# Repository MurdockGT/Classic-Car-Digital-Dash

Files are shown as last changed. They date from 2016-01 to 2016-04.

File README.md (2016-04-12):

# Classic-Car-Digital-Dash
Full digital monitoring of classic car with coolant fan control with Arduino Mega

Current Features  Tested

Coolant Temperature
	AC Delco 213-928 - Connected with 4.7k pull up resistor to create a voltage divider for 
	Arduino to read on port A0 Programmed range 41F to 248F
	Sensor is Non Linear, programmed multiple calibration points to correct the readings.

Intake Air Temp
	AC Delco 213-190 - Connected with 10k pull up resistor to create a voltage divider for 
	Arduino to read on port A1 Programmed range 32f to 158f
	Sensor is Non Linear, programmed multiple calibration points to correct the readings.

Oil Pressure 
	VDO type Oil pressure sender,100 psi,240-33 ohms,low 11 psi alarm/warning switch
	Sensor is linear.  Calculations will be made with 240 to 33 ohm range.  Low PSI warning will also
	be wired into arduino to trigger a low oil alarm.

Battery Level
	Will use a voltage divider and calibration. R1 will be 1m ohm and R2 will be 100k ohms. We will sence from the center
	of R1 and R2.  R2 will be grounded. R1 will go to positive on the battery.
Fan Control - Tempurature dependent with master switch on touchscreen for overide.

Future Additions - Code written, untested

Added code for 4Dsystem 7 inch touchscreen gauge cluster.

Fuel Level indicator  - Code is there for a 80 ohm sending unit, need to calibrate.  This can be adjust in circuit and code for other brand sending units.
	
Wideband Sensor - LSU 4.9 Wideband sensor and controller  14point7.com controller.

Intake manifold pressure   -  http://www.14point7.com/products/boost-vac-sensor

Fuel Pressure - Function is there, same sensor as the Oil pressure gauge.

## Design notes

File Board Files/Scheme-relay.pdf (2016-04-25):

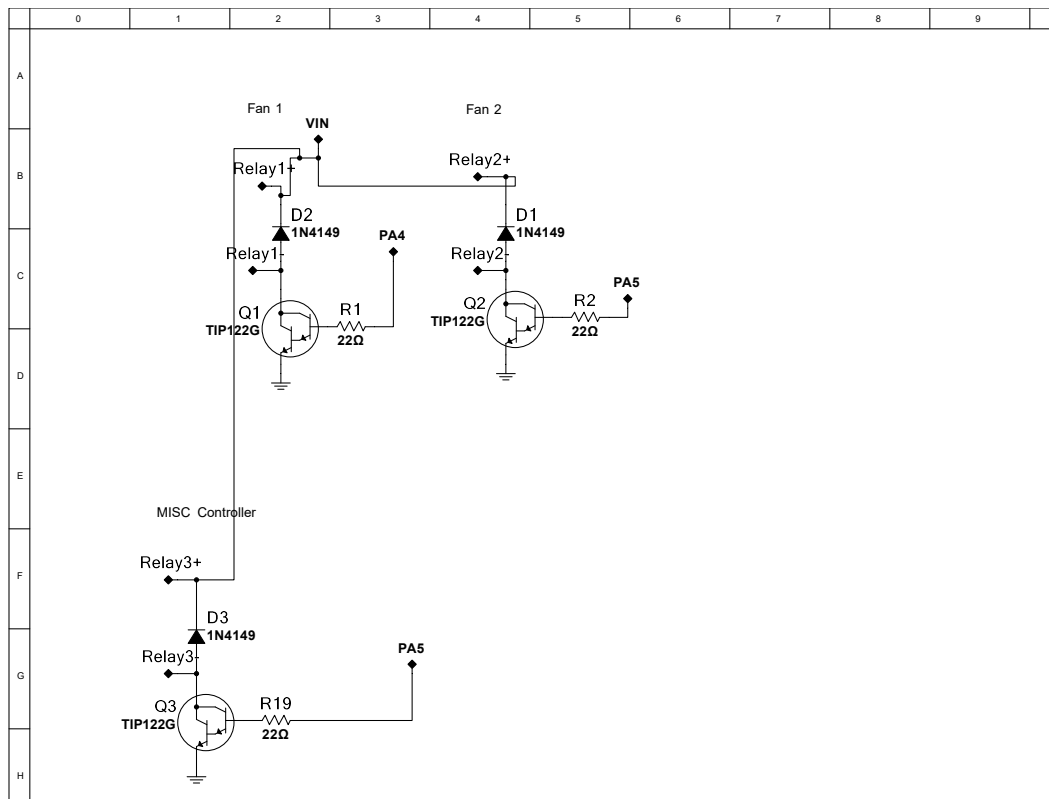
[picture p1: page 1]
TIP122G; Fan 1; Fan 2; MISC Controller; VIN

10 | 11 | 12 | 13 | 14

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
0 | 1 | 2 | 3 | 4 | 5 | 6 | 7 | 8 | 9

I

10 | 11 | 12 | 13 | 14 | I

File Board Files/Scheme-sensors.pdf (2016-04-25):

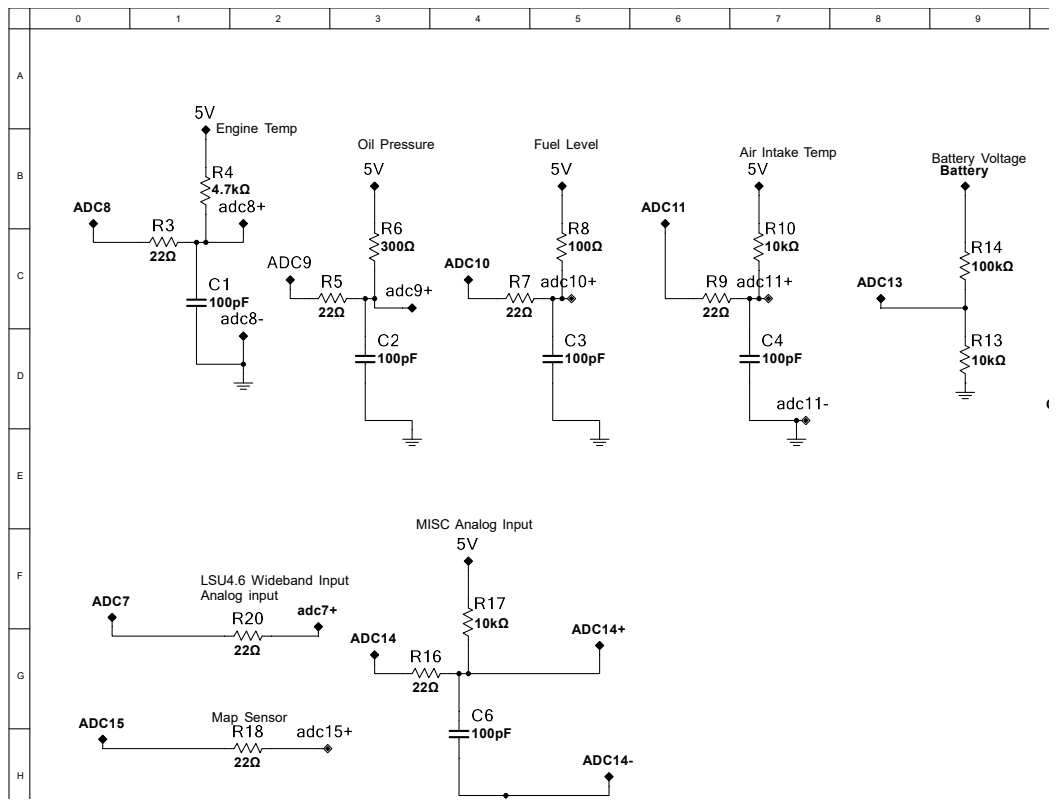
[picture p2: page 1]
Engine Temp; Oil Pressure; Fuel Level; Air Intake Temp; Battery Voltage; LSU4.6 Wideband Input Analog input; Map Sensor 22Ω; Battery; ADC8; ADC10; ADC11; ADC13; OPWL; ADC7; adc7+; ADC14; ADC14+; ADC14-; ADC15

MISC Analog Input

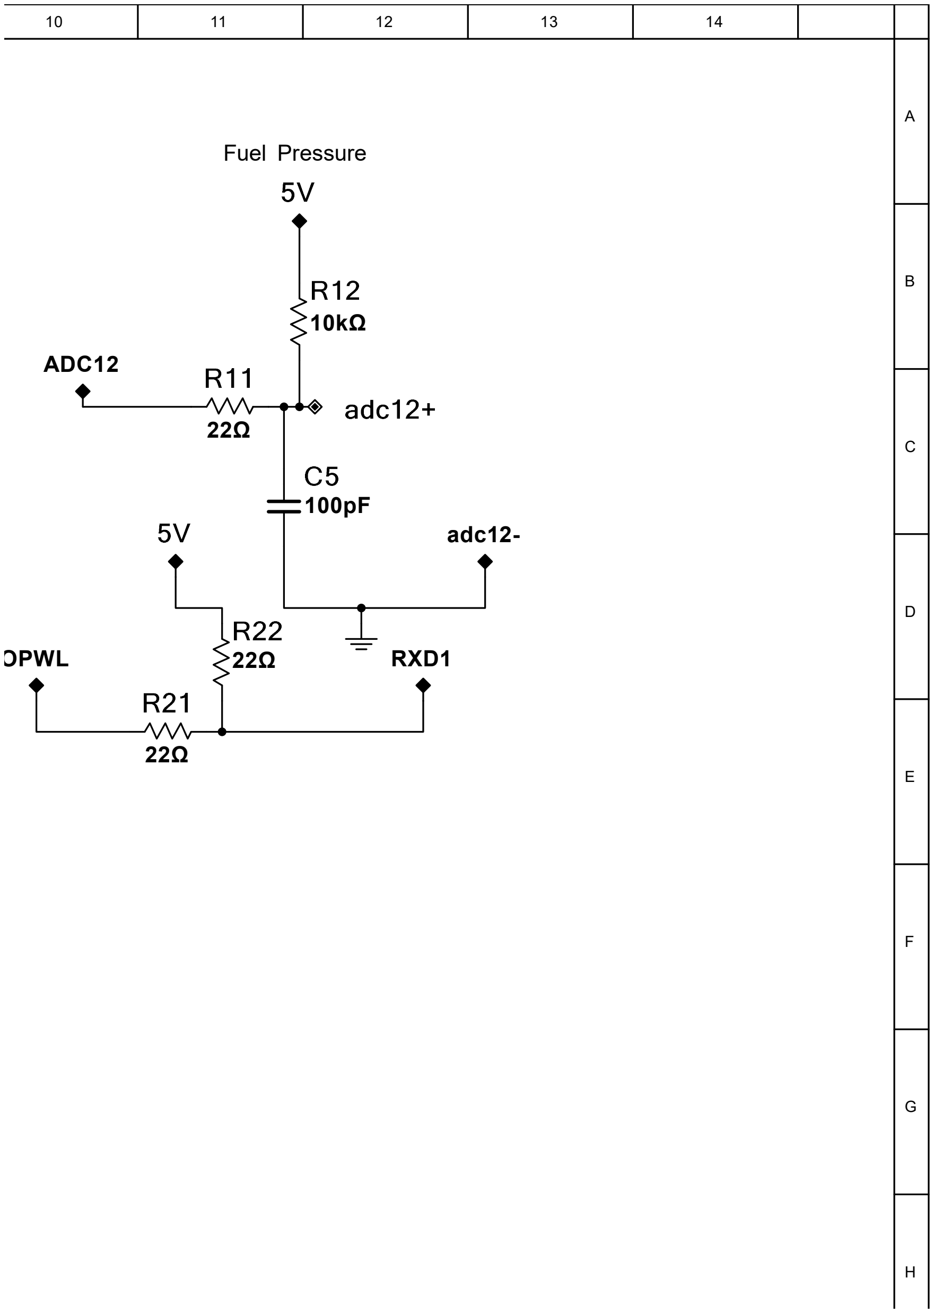
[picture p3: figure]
Fuel Pressure; OPWL; RXD1; ADC12; adc12-

0 | 1 | 2 | 3 | 4 | 5 | 6 | 7 | 8 | 9

I

10 | 11 | 12 | 13 | 14 | I

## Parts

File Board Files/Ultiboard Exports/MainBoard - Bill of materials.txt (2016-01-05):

Ultiboard Information Export File

Design Name  : MainBoard - Bill of materials
Report Date  : 5 January 2016
Report Time  : 06:34
--------------------------------------------------------------------------------

VALUE        SHAPE        #    REFDES       

1N4149       DO-35        3    D1,D2,D3     
4.7kOhm      RES1300-700X250 1    R4           
10kOhm       RES1300-700X250 4    R10,R12,R13,R17
22Ohm        RES1300-700X250 14   R1,R2,R3,R5,R7,R9,R11,R15,R16,R18,R19,R20,R21,R22
100kOhm      RES1300-700X250 1    R14          
100pF        CAPR508-381X254X584 6    C1,C2,C3,C4,C5,C6
100Ohm       RES1300-700X250 1    R8           
300Ohm       RES1300-700X250 1    R6           
HDR1X2       HDR1X2       1    12VIN        
HDR1X3       HDR1X3       1    SERIAL       
HDR1X8       Arduino_HDR1X8 5    ADCH,ADCL,COMMUNICATION,POWER,PWML
HDR1X10      Arduino_HDR1X10 1    JP6          
HDR2X3       HDR2X3       2    RELAY,SDCARD 
HDR2X18      Arduino_HDR2X18 1    XIO          
RIBBON_16V   FKV16SN      1    Sensors      
TIP122G      TO254P482X997X1925-3P 3    Q1,Q2,Q3

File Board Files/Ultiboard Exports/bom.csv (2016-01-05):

RefDes | Value | Shape | Locked | Trace clearance | Part spacing | Pin swap | Gate swap | Part group
12VIN | HDR1X2 | HDR1X2 | No | 0.000000 | Use design rule defaults | Yes | Internal gates only | No group
ADCH | HDR1X8 | Arduino_HDR1X8 | Yes | 0.254000 | Use design rule defaults | Yes | Internal gates only | No group
ADCL | HDR1X8 | Arduino_HDR1X8 | Yes | 0.254000 | Use design rule defaults | Yes | Internal gates only | No group
C1 | 100pF | CAPR508-381X254X584 | No | 0.254000 | Use design rule defaults | Yes | Internal gates only | No group
C2 | 100pF | CAPR508-381X254X584 | No | 0.254000 | Use design rule defaults | Yes | Internal gates only | No group
C3 | 100pF | CAPR508-381X254X584 | No | 0.254000 | Use design rule defaults | Yes | Internal gates only | No group
C4 | 100pF | CAPR508-381X254X584 | No | 0.254000 | Use design rule defaults | Yes | Internal gates only | No group
C5 | 100pF | CAPR508-381X254X584 | No | 0.254000 | Use design rule defaults | Yes | Internal gates only | No group
C6 | 100pF | CAPR508-381X254X584 | No | 0.254000 | Use design rule defaults | Yes | Internal gates only | No group
COMMUNICATION | HDR1X8 | Arduino_HDR1X8 | Yes | 0.254000 | Use design rule defaults | Yes | Internal gates only | No group
D1 | 1N4149 | DO-35 | No | 0.254000 | Use design rule defaults | Yes | Internal gates only | No group
D2 | 1N4149 | DO-35 | No | 0.254000 | Use design rule defaults | Yes | Internal gates only | No group
D3 | 1N4149 | DO-35 | No | 0.254000 | Use design rule defaults | Yes | Internal gates only | No group
JP6 | HDR1X10 | Arduino_HDR1X10 | Yes | 0.254000 | Use design rule defaults | Yes | Internal gates only | No group
POWER | HDR1X8 | Arduino_HDR1X8 | Yes | 0.254000 | Use design rule defaults | Yes | Internal gates only | No group
PWML | HDR1X8 | Arduino_HDR1X8 | Yes | 0.254000 | Use design rule defaults | Yes | Internal gates only | No group
Q1 | TIP122G | TO254P482X997X1925-3P | No | 0.254000 | Use design rule defaults | Yes | Internal gates only | No group
Q2 | TIP122G | TO254P482X997X1925-3P | No | 0.254000 | Use design rule defaults | Yes | Internal gates only | No group
Q3 | TIP122G | TO254P482X997X1925-3P | No | 0.254000 | Use design rule defaults | Yes | Internal gates only | No group
R1 | 22Ohm | RES1300-700X250 | No | 0.254000 | Use design rule defaults | Yes | Internal gates only | No group
R2 | 22Ohm | RES1300-700X250 | No | 0.254000 | Use design rule defaults | Yes | Internal gates only | No group
R3 | 22Ohm | RES1300-700X250 | No | 0.254000 | Use design rule defaults | Yes | Internal gates only | No group
R4 | 4.7kOhm | RES1300-700X250 | No | 0.254000 | Use design rule defaults | Yes | Internal gates only | No group
R5 | 22Ohm | RES1300-700X250 | No | 0.254000 | Use design rule defaults | Yes | Internal gates only | No group
R6 | 300Ohm | RES1300-700X250 | No | 0.254000 | Use design rule defaults | Yes | Internal gates only | No group
R7 | 22Ohm | RES1300-700X250 | No | 0.254000 | Use design rule defaults | Yes | Internal gates only | No group
R8 | 100Ohm | RES1300-700X250 | No | 0.254000 | Use design rule defaults | Yes | Internal gates only | No group
R9 | 22Ohm | RES1300-700X250 | No | 0.254000 | Use design rule defaults | Yes | Internal gates only | No group
R10 | 10kOhm | RES1300-700X250 | No | 0.254000 | Use design rule defaults | Yes | Internal gates only | No group
R11 | 22Ohm | RES1300-700X250 | No | 0.254000 | Use design rule defaults | Yes | Internal gates only | No group
R12 | 10kOhm | RES1300-700X250 | No | 0.254000 | Use design rule defaults | Yes | Internal gates only | No group
R13 | 10kOhm | RES1300-700X250 | No | 0.254000 | Use design rule defaults | Yes | Internal gates only | No group
R14 | 100kOhm | RES1300-700X250 | No | 0.254000 | Use design rule defaults | Yes | Internal gates only | No group
R15 | 22Ohm | RES1300-700X250 | No | 0.254000 | Use design rule defaults | Yes | Internal gates only | No group
R16 | 22Ohm | RES1300-700X250 | No | 0.254000 | Use design rule defaults | Yes | Internal gates only | No group
R17 | 10kOhm | RES1300-700X250 | No | 0.254000 | Use design rule defaults | Yes | Internal gates only | No group
R18 | 22Ohm | RES1300-700X250 | No | 0.254000 | Use design rule defaults | Yes | Internal gates only | No group
R19 | 22Ohm | RES1300-700X250 | No | 0.254000 | Use design rule defaults | Yes | Internal gates only | No group
R20 | 22Ohm | RES1300-700X250 | No | 0.254000 | Use design rule defaults | Yes | Internal gates only | No group
R21 | 22Ohm | RES1300-700X250 | No | 0.254000 | Use design rule defaults | Yes | Internal gates only | No group
R22 | 22Ohm | RES1300-700X250 | No | 0.254000 | Use design rule defaults | Yes | Internal gates only | No group
RELAY | HDR2X3 | HDR2X3 | No | 0.000000 | Use design rule defaults | Yes | Internal gates only | No group
SDCARD | HDR2X3 | HDR2X3 | No | 0.000000 | Use design rule defaults | Yes | Internal gates only | No group
Sensors | RIBBON_16V | FKV16SN | No | 0.000000 | Use design rule defaults | Yes | Internal gates only | No group
SERIAL | HDR1X3 | HDR1X3 | No | 0.000000 | Use design rule defaults | Yes | Internal gates only | No group
XIO | HDR2X18 | Arduino_HDR2X18 | Yes | 0.254000 | Use design rule defaults | Yes | Internal gates only | No group

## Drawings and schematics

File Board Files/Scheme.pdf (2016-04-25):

SC1

## Tach

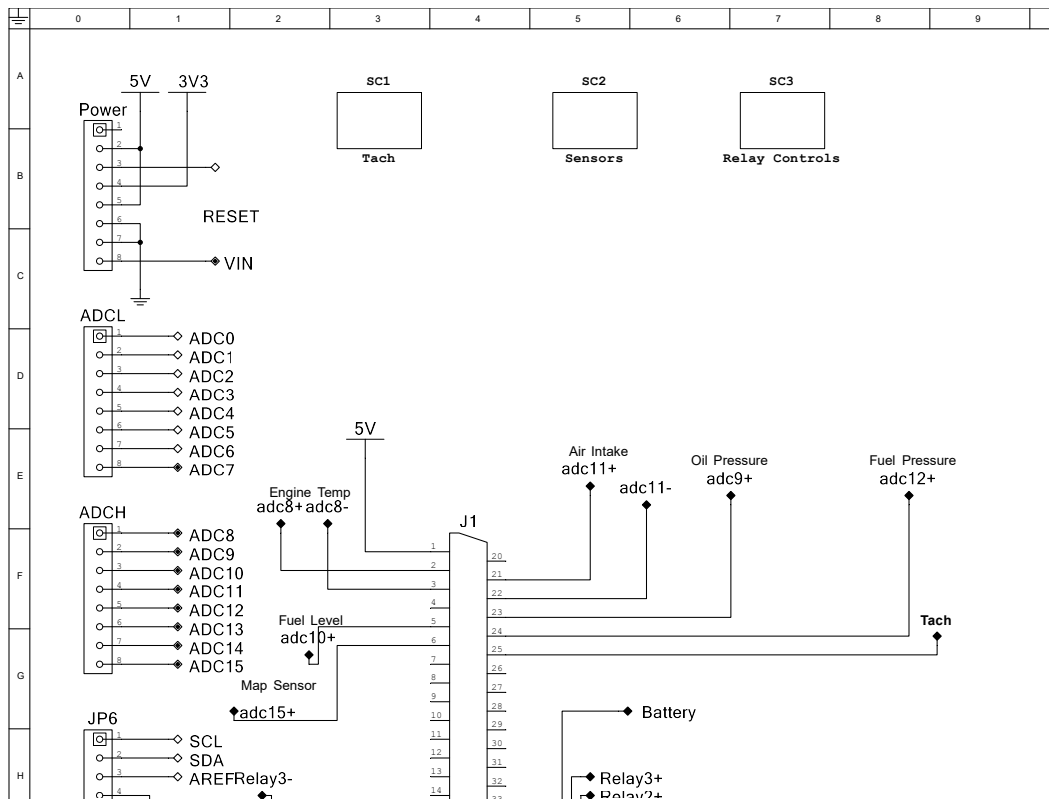
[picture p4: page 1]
Sensors; Relay Controls; Engine Temp; Air Intake; Oil Pressure; Fuel Level; Fuel Pressure; Map Sensor; Tach

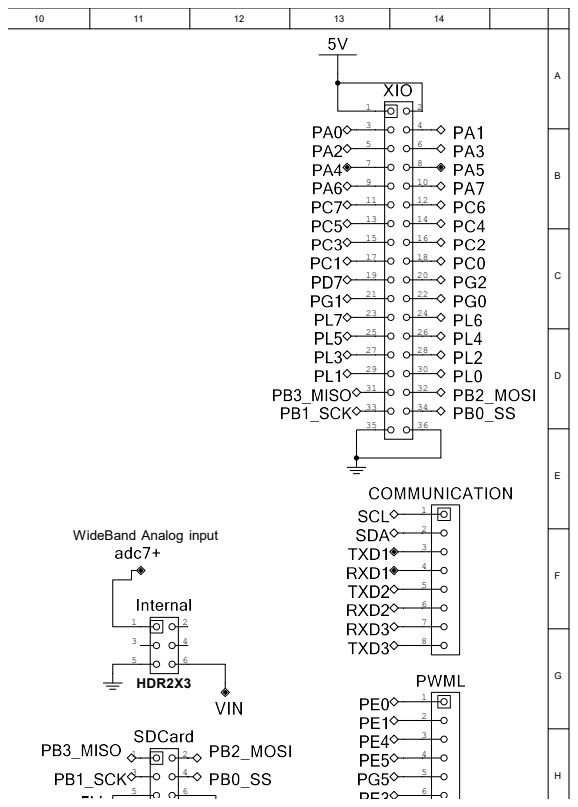
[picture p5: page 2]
HDR2X3

WideBand Analog input

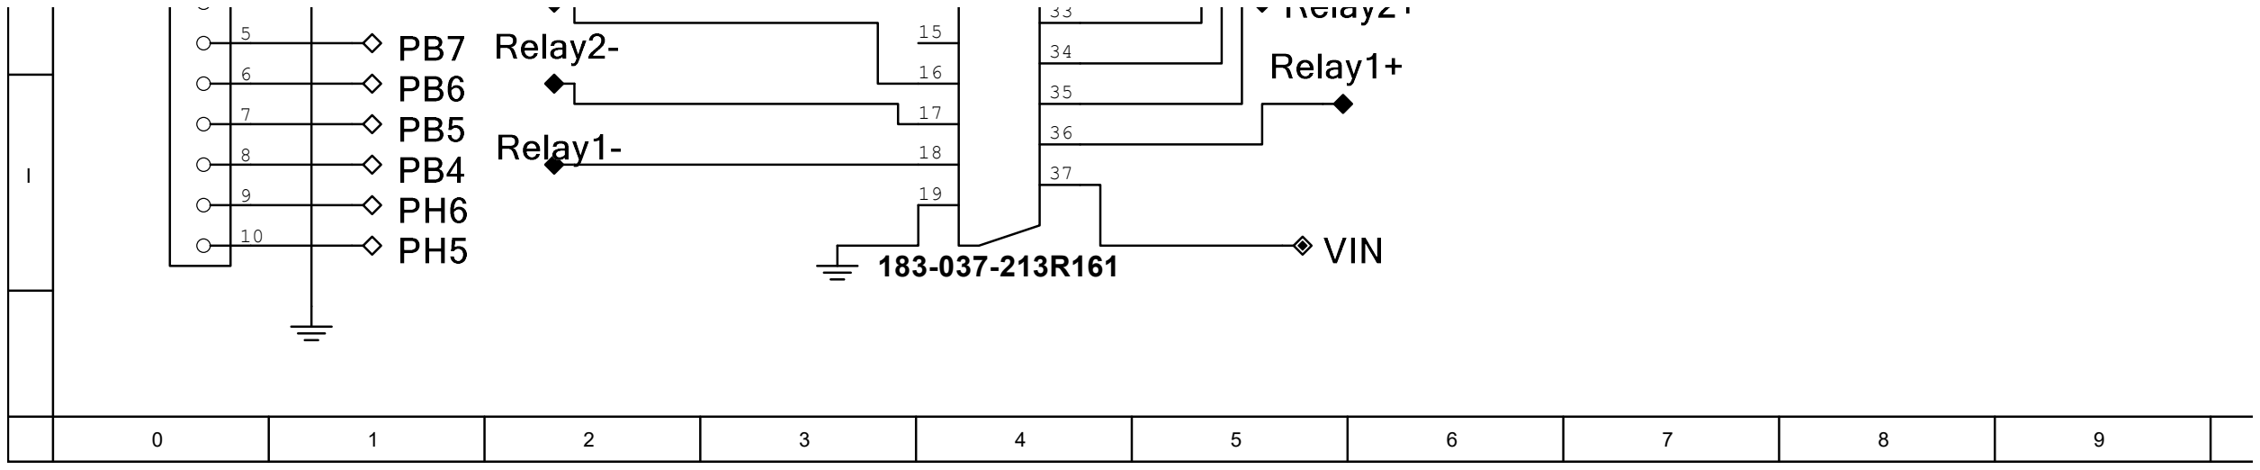
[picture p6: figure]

## HDR2X3

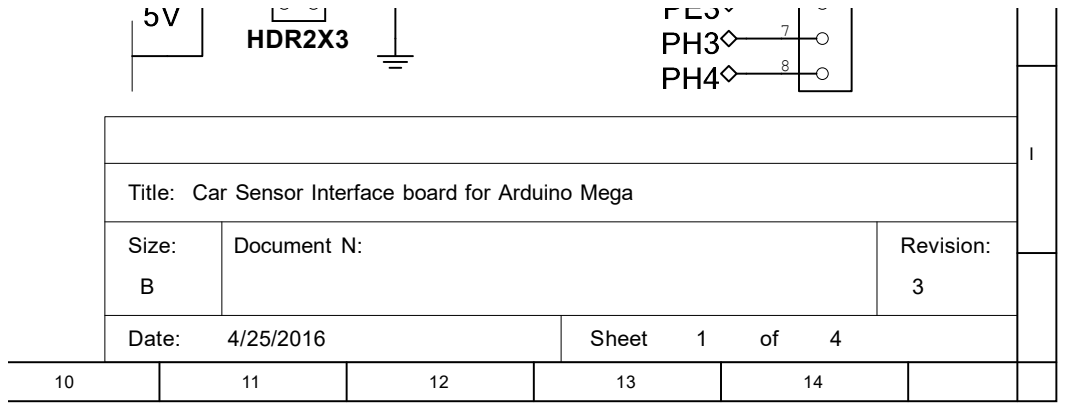
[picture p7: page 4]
Title:; Document N:; Date:; Sheet; Size:; Revision:

Car Sensor Interface board for Arduino Mega

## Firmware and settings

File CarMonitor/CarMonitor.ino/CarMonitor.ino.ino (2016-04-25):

#include <genieArduino.h>
#include <Wire.h>
#include <math.h>
#include <EEPROM.h>
// #include <Time.h>


// Configuration
int targetCoolantTemp = 180; // this is the target for the fans to turn on.
int targetChokeTemp = 120;// set a tempurature that you want the choke to be turned off at.
int fuelGaugeOhms = 80;


// analog pins

const byte AFRatioPin = A7; // pin for LSU 4.9 O2 sensor controller linear output
const byte coolantTempPin = A8; // pin for coolant temp
const byte oilPressPin = A9; // pin for oil pressure
const byte fuelLevelPin = A10; // pin for fuel level
const byte iatTempPin = A11;  // Air intake temperature
const byte fuelPressPin = A12; // Fuel Line Pressure Pin
const byte battVoltagePin = A13; // pin for battery voltage
const byte MiscAnalogInput = A14;  // Placeholder for another analog input. Not used as of now, but circuit is there on board.
const byte intakePressPin = A15; // pin for intake manifold pressure (vac or boost)

// analog input setup
const float aRef = 5.0; // analog reference for board (Volts)
const float regVoltage = 5.0; // instrument unit voltage regulator output (Volts)

//digital Pins

const byte oilWarninglight = 18; // pin for showing if oil pressure has dropped below 11 psi
const byte wireSDAPin = 20; // I2C SDA
const byte wireSCLPin = 21; // I2C SCL

// Fan status Bool
int switch1Val;
bool fanStatus1 = 0;
bool fanStatus2 = 0;

// Steinhart–Hart equation parameters for coolant temp sender
// http://en.wikipedia.org/wiki/Thermistor
const float SHparamA = 1.869336e-3;
const float SHparamB = 2.723037e-4;
const float SHparamC = 2.833889e-7;

unsigned long previousMillis = 0; // for sensor refresh interval

// engine info
byte engineCylinders = 8; // for future use

int displacement = 302; // (units of cu in) for MAFR calculations
int refreshInterval = 750; // milliseconds between sensor updates


//configuration for the Tachometer variables
byte engineCycles = 4; // for tach calculation :Future use
const int tachSensorPin = 19;
const int sensorInterrupt = 4;
const int timeoutValue = 5;
volatile unsigned long lastPulseTime;
volatile unsigned long interval = 0;
volatile int timeoutCounter;
int rpm;
int rpmlast = 3000;
int rpm_interval = 3000;
const int fanOut1 = 6; // need to move from pin 4 to pin 6, Screen needs this for reset, will move it on next test board to pin 6.
const int fanOut2 = 5;
const int eChoke = 22;  // Pin assignment for Choke engagment if you have an electronic choke.

Genie genie;
#define RESETLINE 2  // Change this if you are not using an Arduino Adaptor Shield Version 2 (see code below)

void setup() {
  Serial.begin(200000);  // Serial0 @ 200000 (200K) Baud
  genie.Begin(Serial);   // Use Serial0 for talking to the Genie Library, and to the 4D Systems display

  genie.AttachEventHandler(myGenieEventHandler); // Attach the user function Event Handler for processing events
  // Reset the Display (change D4 to D2 if you have original 4D Arduino Adaptor)
  // THIS IS IMPORTANT AND CAN PREVENT OUT OF SYNC ISSUES, SLOW SPEED RESPONSE ETC
  // If NOT using a 4D Arduino Adaptor, digitalWrites must be reversed as Display Reset is Active Low, and
  // the 4D Arduino Adaptors invert this signal so must be Active High.
  pinMode(RESETLINE, OUTPUT);  // Set D4 on Arduino to Output (4D Arduino Adaptor V2 - Display Reset)
  digitalWrite(RESETLINE, 1);  // Reset the Display via D4
  delay(100);
  digitalWrite(RESETLINE, 0);  // unReset the Display via D4

  delay (3500); //let the display start up after the reset (This is important)

  // Set the brightness/Contrast of the Display - (Not needed but illustrates how)
  // Most Displays, 1 = Display ON, 0 = Display OFF. See below for exceptions and for DIABLO16 displays.
  // For uLCD-43, uLCD-220RD, uLCD-70DT, and uLCD-35DT, use 0-15 for Brightness Control, where 0 = Display OFF, though to 15 = Max Brightness ON.
  genie.WriteContrast(15);

  //Write a string to the Display to show the version of the library used
  genie.WriteStr(0, GENIE_VERSION);

  Serial.begin(9600); // initialize serial communication at 9600 bits per second:
  // Fan Pin Setup
  pinMode(fanOut1, OUTPUT);
  pinMode(fanOut2, OUTPUT);
  pinMode(eChoke, OUTPUT);
  digitalWrite(fanOut1, LOW);
  digitalWrite(fanOut2, LOW);
  // Tach Setup
  pinMode(tachSensorPin, INPUT);
  attachInterrupt(sensorInterrupt, sensorIsr, RISING);
  lastPulseTime = micros();
  timeoutCounter = 0;


}





// the loop routine runs over and over again forever:
void loop() {

  static long waitPeriod = millis(); // Time now

  static int gaugeOilp = getOilpressure();
  static int gaugeEngineTemp = getCoolantTemp();
  static int gaugeIntakeTemp = getIATtemp();
  static int gaugeIntakePress = getIntakePress();
  static int gaugeVoltage = getBattVoltage();
  static int gaugeRPM = getRPM();
  static int gaugeAFratio = getAFRatio();
  static int gaugeFuelPress = getFuelPress();
  static int gaugeFuelLevel = getFuelLevel();

  fanControl(gaugeEngineTemp); // controls fan

  // write the values to the 4DS Screen.
  // Gauge name, Gauge number, Gauge Value
  genie.WriteObject(GENIE_OBJ_COOL_GAUGE, 0, gaugeAFratio); //GENIE_OBJ_ANGULAR_METER
  genie.WriteObject(GENIE_OBJ_COOL_GAUGE, 1, gaugeRPM);
  genie.WriteObject(GENIE_OBJ_ANGULAR_METER, 0, gaugeIntakeTemp);
  genie.WriteObject(GENIE_OBJ_ANGULAR_METER, 1, gaugeEngineTemp);
  genie.WriteObject(GENIE_OBJ_ANGULAR_METER, 2, gaugeVoltage);
  genie.WriteObject(GENIE_OBJ_ANGULAR_METER, 3, gaugeFuelLevel);
  genie.WriteObject(GENIE_OBJ_ANGULAR_METER, 4, gaugeIntakePress);
  genie.WriteObject(GENIE_OBJ_ANGULAR_METER, 5, gaugeOilp);

  genie.ReadObject(GENIE_OBJ_4DBUTTON, 0);

}
void myGenieEventHandler(void)
{
  genieFrame Event;
  genie.DequeueEvent(&Event); // Remove the next queued event from the buffer, and process it below


  if (genie.EventIs(&Event, GENIE_REPORT_OBJ, GENIE_OBJ_4DBUTTON, 0))
  { //if the event is a REPORT_OBJ from 4DBUTTON3
    switch1Val = genie.GetEventData(&Event);  //extract the MSB and LSB values and pass them to rockersw_val

  }

}
int getCoolantTemp()
{
  // Using AC Delco/GM 2 wire temp sensor.
  float array[44] = {
    // Voltage From Sensor on left // Corresponding Temprature on right  ,
    //You find this by using voltage divider forumla. Current set is for a 4.7k ohm R1 and R2 is your ACdelco Temp Sensor
    2.429165  , 15 ,
    2.137986  , 20 ,
    1.864576  , 25 ,
    1.613833  , 30 ,
    1.38795   , 35 ,
    1.188159  , 40,
    1.013571  , 45,
    0.8626761 , 50,
    0.734253  , 55,
    0.6246509 , 60,
    0.5314699 , 65,
    0.4536661 , 70,
    0.3876349 , 75,
    0.3317441 , 80,
    0.286803  , 85,
    0.2446477 , 90,
    0.2110208 , 95,
    0.1824518 , 100,
    0.1582331 , 105,
    0.1376963 , 110,
    0.1201279 , 115,
    0.1050845 , 120,
  };

  int val = 0;
  for (int i = 1; i <= 10; i++)
  {
    val += analogRead(coolantTempPin);
  }
  val += 5; // allows proper rounding due to using integer math
  val /= 10; // get average value
  float voltage = val / 1023.0 * aRef;
  float tempr;
  if (voltage >= array[0])
  {
    tempr = array[1];
  }
  else if (voltage <= array[42])
  {
    tempr = array[43];
  }
  else
  {
    for (int i = 1; i < 44; i++)
    {
      int ii = 2 * i;
      if (voltage <= array[ii] && voltage >= array[ii + 2])
      {
        tempr = array[ii + 1] + ((array[ii + 3] - array[ii + 1]) * (voltage - array[ii]) / (array[ii + 2] - array[ii]));
        break;
      }
    }
  }
  int temprF = tempr * 1.8 + 32;
  return temprF;
}
int getOilpressure()
{
  // using VDO Oil Pressure guage, 100PSI
  float array[12] = {
    // Voltage From Sensor on left // Corresponding Temprature on right  ,
    //You find this by using voltage divider forumla. Current set is for a 330 ohm R1 and R2 is your VDO Oil Pressure sensor

    2.105263 , 0.1,
    1.944444 , 14.5,
    1.764706 , 29,
    1.5625 , 43.5,
    1.071429 , 72.5,
    0.4141189 , 100,
  };
  int val = 0;
  for (int i = 1; i <= 10; i++)
  {
    val += analogRead(oilPressPin);
  }
  val += 5; // allows proper rounding due to using integer math
  val /= 10; // get average value
  float voltage = val / 1023.0 * aRef;

  float oilp;
  if (voltage >= array[0])
  {
    oilp = array[1];
  }
  else if (voltage <= array[10])
  {
    oilp = array[11];
  }
  else
  {
    for (int i = 1; i < 12; i++)
    {
      int ii = 2 * i;
      if (voltage <= array[ii] && voltage >= array[ii + 2])
      {
        oilp = array[ii + 1] + ((array[ii + 3] - array[ii + 1]) * (voltage - array[ii]) / (array[ii + 2] - array[ii]));
        break;
      }
    }
  }
  int oilpres = oilp;
  return oilpres;
}
int getIATtemp()
{

  float array[30] = {
    // Voltage From Sensor on left // Corresponding Temprature on right  ,
    //You find this by using voltage divider forumla. Current set is for a 10k ohm R1 and R2 is your ACdelco Temp Sensor

    2.403407 , 0,
    2.085058 , 5,
    1.789109 , 10,
    1.526089 , 15,
    1.284462 , 20,
    1.079046 , 25,
    0.9033183 , 30,
    0.7547971 , 35,
    0.6305165 , 40,
    0.5265277 , 45,
    0.4400365 , 50,
    0.3686551 , 55,
    0.3095685 , 60,
    0.2611127 , 65,
    0.2207991 , 70,


  };

  int val = 0;
  for (int i = 1; i <= 10; i++)
  {
    val += analogRead(iatTempPin);
  }
  val += 5; // allows proper rounding due to using integer math
  val /= 10; // get average value
  float voltage = val / 1023.0 * aRef;



  float temprIAT;
  if (voltage >= array[0])
  {
    temprIAT = array[1];
  }
  else if (voltage <= array[28])
  {
    temprIAT = array[29];
  }
  else
  {
    for (int i = 1; i < 44; i++)
    {
      int ii = 2 * i;
      if (voltage <= array[ii] && voltage >= array[ii + 2])
      {
        temprIAT = array[ii + 1] + ((array[ii + 3] - array[ii + 1]) * (voltage - array[ii]) / (array[ii + 2] - array[ii]));
        break;
      }
    }
  }
  int temprFIAT = temprIAT * 1.8 + 32;
  return temprFIAT;
}
float getIntakePress()
{
  // will need to test with this sensor and moddify from there.
  // http://www.14point7.com/products/boost-vac-sensor
  // take 10 readings and sum them
  int val = 0;
  for (int i = 1; i <= 10; i++)
  {
    val += analogRead(intakePressPin);
  }
  val += 5; // allows proper rounding due to using integer math
  val /= 10; // get average value
  float volts = val / 1023.0 * aRef;
  float pressure = 0;
  if (volts <= 1.0)
  {
    pressure = 29.0 * volts - 29.0; // vac
  }
  else
  {
    pressure = 14.5 * volts - 14.5; // boost
  }
  return pressure;
}
float getAFRatio()
{
  float currentAFRatio = getLambda() * 14.7; // convert to Air/Fuel Mass Ratio (Air/Gasoline)
  int currentAFRatioInt = int(currentAFRatio * 10 + 0.5);
  byte lastDigit = currentAFRatioInt % 10;
  currentAFRatioInt /= 10;
  return currentAFRatioInt;
}
float getFuelPress()
{
  // using VDO  Pressure guage, 100PSI
  float array[12] = {
    // Voltage From Sensor on left // Corresponding Temprature on right  ,
    //You find this by using voltage divider forumla. Current set is for a 330 ohm R1 and R2 is your VDO Oil Pressure sensor

    2.105263 , 0.1,
    1.944444 , 14.5,
    1.764706 , 29,
    1.5625 , 43.5,
    1.071429 , 72.5,
    0.4141189 , 100,
  };


  int val = 0;
  for (int i = 1; i <= 10; i++)
  {
    val += analogRead(fuelPressPin);
  }
  val += 5; // allows proper rounding due to using integer math
  val /= 10; // get average value
  float voltage = val / 1023.0 * aRef;
  float fuelp;
  if (voltage >= array[0])
  {
    fuelp = array[1];
  }
  else if (voltage <= array[10])
  {
    fuelp = array[11];
  }
  else
  {
    for (int i = 1; i < 12; i++)
    {
      int ii = 2 * i;
      if (voltage <= array[ii] && voltage >= array[ii + 2])
      {
        fuelp = array[ii + 1] + ((array[ii + 3] - array[ii + 1]) * (voltage - array[ii]) / (array[ii + 2] - array[ii]));
        break;
      }
    }
  }
  int fuelpres = fuelp;
  return fuelpres;
}

float getBattVoltage()
{
  // reads input voltage
  // returns battery voltage in Volts
  // resolution: 0.0176 V = 17.6 mV
  // Voltage divider maps 18 V to 5 V
  float R1 = 100000.0; // value of R1 in voltage divider (ohms)
  float R2 = 9900.0; // value of R2 in voltage divider (ohms)
  // take 10 readings and sum them
  int val = 0;
  for (int i = 1; i <= 10; i++)
  {
    val += analogRead(battVoltagePin);
  }
  val += 5; // allows proper rounding due to using integer math
  val /= 10; // get average value
  float Vout = (val / 1023.0) * aRef; // convert 10-bit value to Voltage
  float Vin = Vout * (R1 + R2) / R2; // solve for input Voltage
  return Vin; // return calculated input Voltage
}
float getFuelLevel()
{
  // using Factory 80 ohm Fuel Sender(can be adjusted for others.
  float array[12] = {
    // Voltage From Sensor on left // Corresponding Temprature on right  ,
    //You find this by using voltage divider forumla. Current set is for a 330 ohm R1 and R2 is your VDO Oil Pressure sensor

    2.105263 , 0.1,
    1.944444 , 14.5,
    1.764706 , 29,
    1.5625 , 43.5,
    1.071429 , 72.5,
    0.4141189 , 100,
  };
  int val = 0;
  for (int i = 1; i <= 30; i++)
  {
    val += analogRead(fuelLevelPin);
  }
  val += 5; // allows proper rounding due to using integer math
  val /= 10; // get average value
  float voltage = val / 1023.0 * aRef;

  float level;
  if (voltage >= array[0])
  {
    level = array[1];
  }
  else if (voltage <= array[10])
  {
    level = array[11];
  }
  else
  {
    for (int i = 1; i < 12; i++)
    {
      int ii = 2 * i;
      if (voltage <= array[ii] && voltage >= array[ii + 2])
      {
        level = array[ii + 1] + ((array[ii + 3] - array[ii + 1]) * (voltage - array[ii]) / (array[ii + 2] - array[ii]));
        break;
      }
    }
  }

  level = constrain(level, 0, 100); // constrain level to between 0 and 100 (inclusive)
  return level; // return fuel level in %
}
float getLambda()
{
  // reads analog output of LSU 4.9 O2 sensor driver (0-5 V)
  // 0 V = 0.68 lambda
  // 5 V = 1.36 lambda
  // returns Lambda value (dimensionless)
  // resolution: 0.000665 = 0.01 A/F
  // take 10 readings and sum them
  int val = 0;
  for (int i = 1; i <= 10; i++)
  {
    val += analogRead(AFRatioPin);
  }
  val += 5; // allows proper rounding due to using integer math
  val /= 10; // get average value
  float lambda = (map(val, 0, 1023, 680, 1360)) / 1000.0; // calculate lambda value avoiding limitations of map()
  return lambda;
}
int getRPM()
{
  // checks accumulated tach signal pulses and calculates engine speed
  // returns engine speed in RPM
  // Resolution: 30000 * engineCycles / refreshInterval / engineCylinders RPM (for default values = 20 RPM)
  if (timeoutCounter != 0)
  {
    --timeoutCounter;

    //This calculation will need to be calibrated for each application
    rpm = 60e6 / (float)interval; // ORIGINAL



  }

  //remove erroneous results
  if (rpm > rpmlast + 500) {
    rpm = rpmlast;
  }

  rpmlast = rpm;
  rpm = constrain(rpm, 0, 8000);

  return rpm;

}
void sensorIsr()
{
  unsigned long now = micros();
  interval = now - lastPulseTime;
  lastPulseTime = now;
  timeoutCounter = timeoutValue;
}
void fanControl(float a)
{

  if (switch1Val == 0)
  {
    if (a >= targetCoolantTemp)
    {
      digitalWrite(fanOut1, HIGH); // statment to turn on fan Digital output.
      digitalWrite(fanOut2, HIGH);              // set pin high
      fanStatus1 = true;
      fanStatus2 = true;
    }
    else if (a <= targetCoolantTemp)
    {
      //Statement to turn fan digital output off.
      digitalWrite(fanOut1, LOW);
      digitalWrite(fanOut2, LOW);
      fanStatus1 = false;
      fanStatus1 = false;
    }

  }
  else
  {
    fanStatus1 = true;
    fanStatus2 = true;
  }

}
void choke()
{
  // set pin 22 high if temp is under 120F
  int engineTempF = getCoolantTemp();
  if (engineTempF < targetChokeTemp)
  {
    digitalWrite(eChoke, HIGH);
  }
  else
  {
    digitalWrite(eChoke, LOW);
  }

}

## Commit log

2015-11-21 Added Voltage reading function
2016-01-02 Added link to Boost sensor used by the code from SeanAuff
2016-01-03 Added Board design Files
    Added Multisim Schem. of the circuit. Added Ultiboard file as well.
    Board is designed for a 4 layer construction. Attached Gerber files for
    board assembly. I have not gotten the board made yet. Make at own
    risk.
2016-01-03 Changed Tach Interrupt
2016-01-04 Fan and Choke changes
    Added Fan 1 and 2, instead of one fan total. Added code to use Misc
    relay control to control the E-Choke on the Carberrator.
2016-01-05 board updates
    [MainBoard - Board Outline.gbr, MainBoard - Copper Bottom.gbr, MainBoard - Copper Inner 1.gbr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]
2016-04-12 Multiple Updates
    Cleaned up code, added 4ds screen information, added remaining sensor
    code.
